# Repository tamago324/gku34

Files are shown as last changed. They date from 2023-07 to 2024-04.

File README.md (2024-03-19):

# gku34

* 狭ピッチ
  * キーピッチが縦17mmx横18mm
* KiCad 6 で作成
* [horizon プラグイン](https://github.com/skarrmann/horizon/blob/5833ec133d5f8fa4f3824622efd5dbfc89d797ec/kicad-plugins/horizon-board-producer-plugin.py)を使ってボトムプレートを生成
* choc v1 (rev0.1, rev0.2)
* Lofree switch (rev0.3)

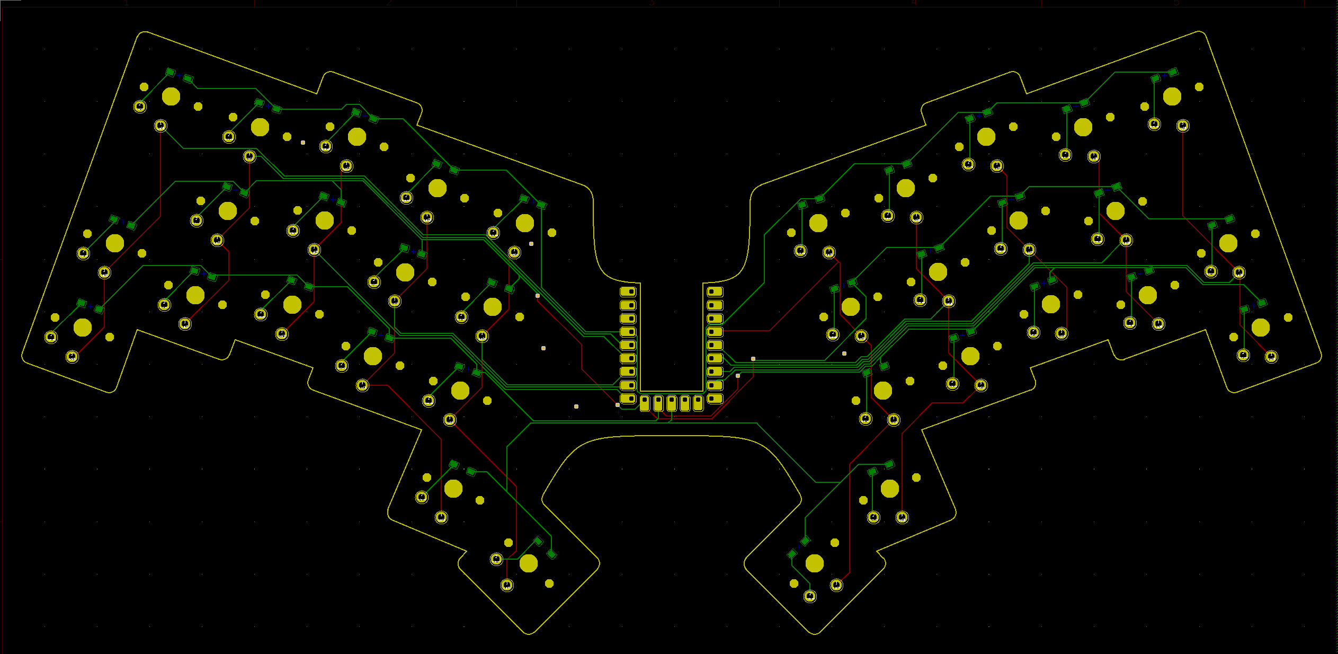
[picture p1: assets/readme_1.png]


## LICENSE

<br />この作品は <a rel="license" href="http://creativecommons.org/licenses/by/4.0/">クリエイティブ・コモンズ 表示 4.0 国際 ライセンス</a>の下に提供されています。

> 共有 — どのようなメディアやフォーマットでも資料を複製したり、再配布できます。
> 
> 翻案 — マテリアルをリミックスしたり、改変したり、別の作品のベースにしたりできます。営利目的も含め、どのような目的でも。

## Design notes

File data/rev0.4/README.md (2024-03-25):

* [Lofree スイッチ](https://www.lofree.co/products/lofree-x-kailh-full-pom-low-profile-switches)を使えるようにした
  * Choc V1 も使える
* rev0.3 との違い
  * 配線をF.cu側に集めた
    * スイッチの交換をするときに、配線に傷がつかないようにするため

## 発注するとき (JLCPCB)

* 基板
  * main_pcb (メイン基板)
    * `gerbers/main_pcb/gku34_247.632052x114.711068mm_for_JLCPCB.zip`
      * PCB Thickness: 1.6mm
      * Remove Order Number: Specify a location
  * bottom_plate (ボトムプレート)
    * `gerbers/bottom_plate/gku34-bottom-plate_247.632052x114.711068mm_for_JLCPCB.zip`
      * PCB Thickness: 1.6mm
      * Remove Order Number: Specify a location
* トッププレート
  * `stl/gku34-top-plate-jlcpcb.stl`
    * 3D Technology: MJF(Nylon)
    * Material: PA12-HP Nylon
    * Color: Black

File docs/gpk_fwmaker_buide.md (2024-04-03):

## GPK FWMaker でのビルド方法について

QMK のファームウェアをビルドするために[GPK FWMaker](https://github.com/darakuneko/gpk_fwmaker) が使用できます。
Docker を使用して簡単にビルドできるのでオススメです。

### Docker のインストール

https://www.docker.com/ から環境にあったものをダウンロードし、インストールします。

インストールが完了したらPCの再起動します。

### GPK FWMaker のダウンロード

https://github.com/darakuneko/gpk_fwmaker/archive/refs/heads/main.zip でダウンロードします。

### 初期セットアップ

ダウンロードしたディレクトリに移動し、

```
cd gpk_fwmaker
docker compose build
```

を実行。

### ツールの起動

```
cd gpk_fwmaker
docker compose up -d
```

### QMKのキーボードディレクトリをコピーする

GPKFW ディレクトリに QMKの [keyboards/tamago324/gku34](https://github.com/tamago324/qmk_firmware/tree/tamago324_v2/keyboards/tamago324/gku34) ディレクトリを、環境に合わせて以下のディレクトリにコピーする

windows: `C:\Users\xxxx\GPKFW`
mac: `/Users/xxxx/GPKFW`
ubuntu: `/home/xxxx/GPKFW`

例えば、Windows の場合、`C:\Users\xxxx\GPKFW\gku34` にコピーする

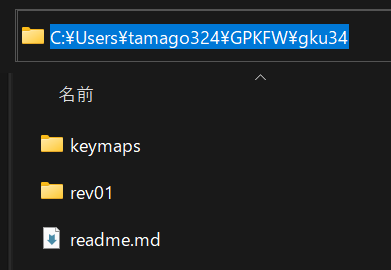
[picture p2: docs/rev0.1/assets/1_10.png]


### ファームウェアの作成

以下のコマンドを実行し、ファームウェアを作成する

Windows の場合:

```
# qmk の場合
curl -X POST -H "Content-Type: application/json" -d "{\"kb\": \"gku34/rev01\", \"km\": \"default\", \"tag\": \"0.21.5\"}" 127.0.0.1:3123/build/qmk

# vial の場合
curl -X POST -H "Content-Type: application/json" -d "{\"kb\": \"gku34/rev01\", \"km\": \"vial\"}" 127.0.0.1:3123/build/vial
```

`C:\Users\xxxx\GPKFW` に `gku34_rev01_default.uf2` が生成される

Linux の場合:

```
# qmk
curl -X POST -H "Content-Type: application/json" -d '{"kb": "gku34/rev01", "km": "tamago324", "tag": "0.21.5"}" 127.0.0.1:3123/build/qmk

# vial
curl -X POST -H "Content-Type: application/json" -d '{"kb": "gku34/rev01", "km": "vial"}' 127.0.0.1:3123/build/vial
```

### ファームウェアの書き込み

RP2040-Zero の左側のボタンを押しながら、USB を接続する

新しいデバイスとしてファイルエクスプローラに表示された、キーボードに生成された `gku34_rev01_default.uf2` をコピーします。コピーが完了すると、デバイスが切断されます。

デバイスが切断されたら、ファームウェアの書き込みが完了です。

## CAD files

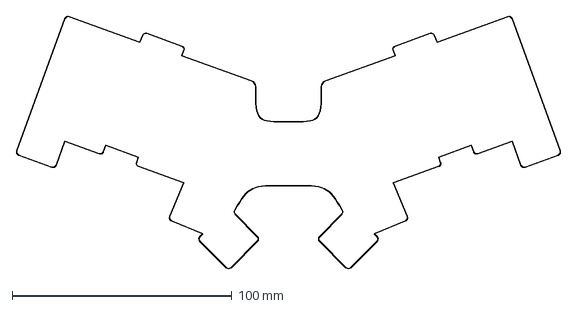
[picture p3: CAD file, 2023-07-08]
data/rev0.4/dxf/edge-bottom.dxf
248.0 x 115.1 mm

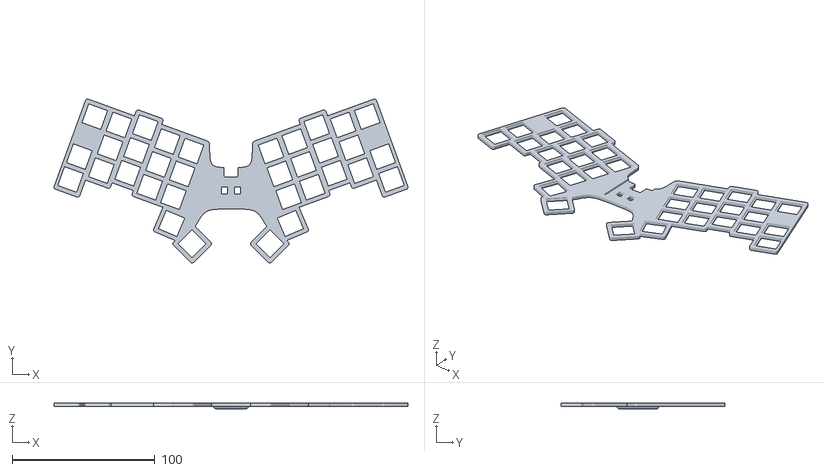
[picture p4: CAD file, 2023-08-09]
data/rev0.4/stl/gku34-top-plate-jlcpcb.stl
247.6 x 114.8 x 4.00

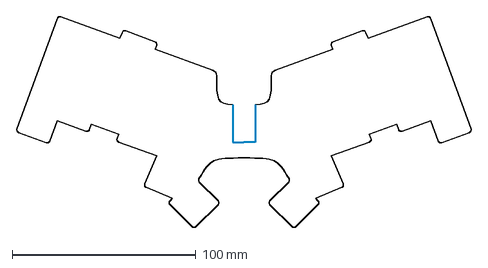
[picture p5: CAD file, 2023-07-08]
data/rev0.4/dxf/edge-pcb.dxf
248.0 x 115.1 mm

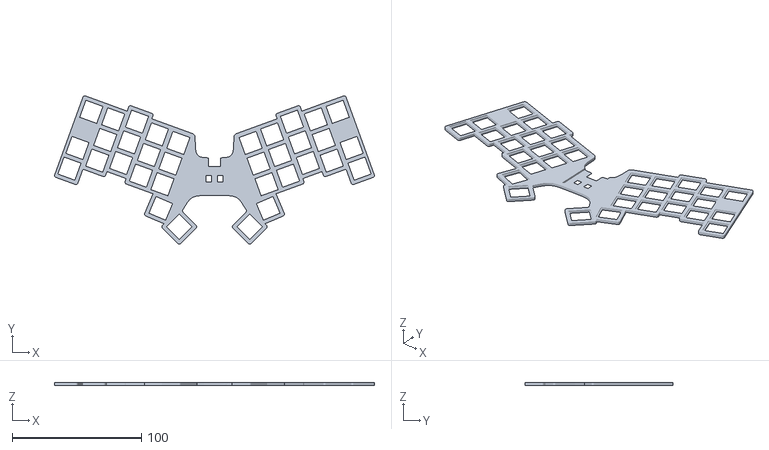
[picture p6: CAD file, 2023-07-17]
data/rev0.4/stl/gku34-top-plate.stl
247.6 x 114.8 x 2.20

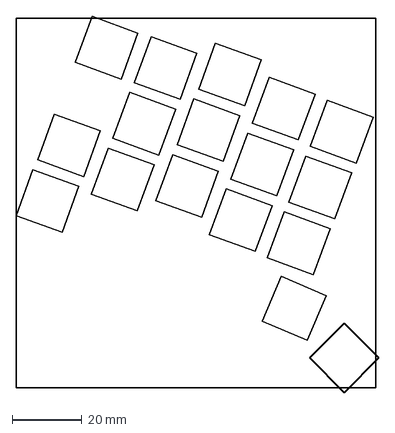
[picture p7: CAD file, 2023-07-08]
data/rev0.4/dxf/layout-base.dxf
103.9 x 107.8 mm

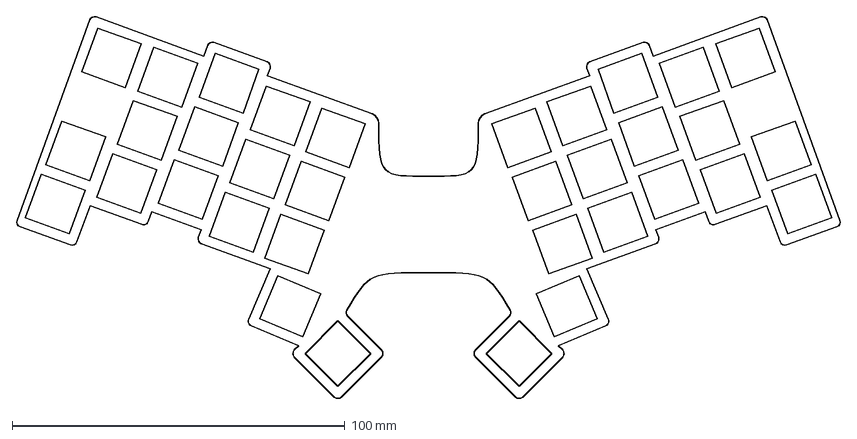
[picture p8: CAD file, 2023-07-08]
data/rev0.4/dxf/support.dxf
248.0 x 115.1 mm

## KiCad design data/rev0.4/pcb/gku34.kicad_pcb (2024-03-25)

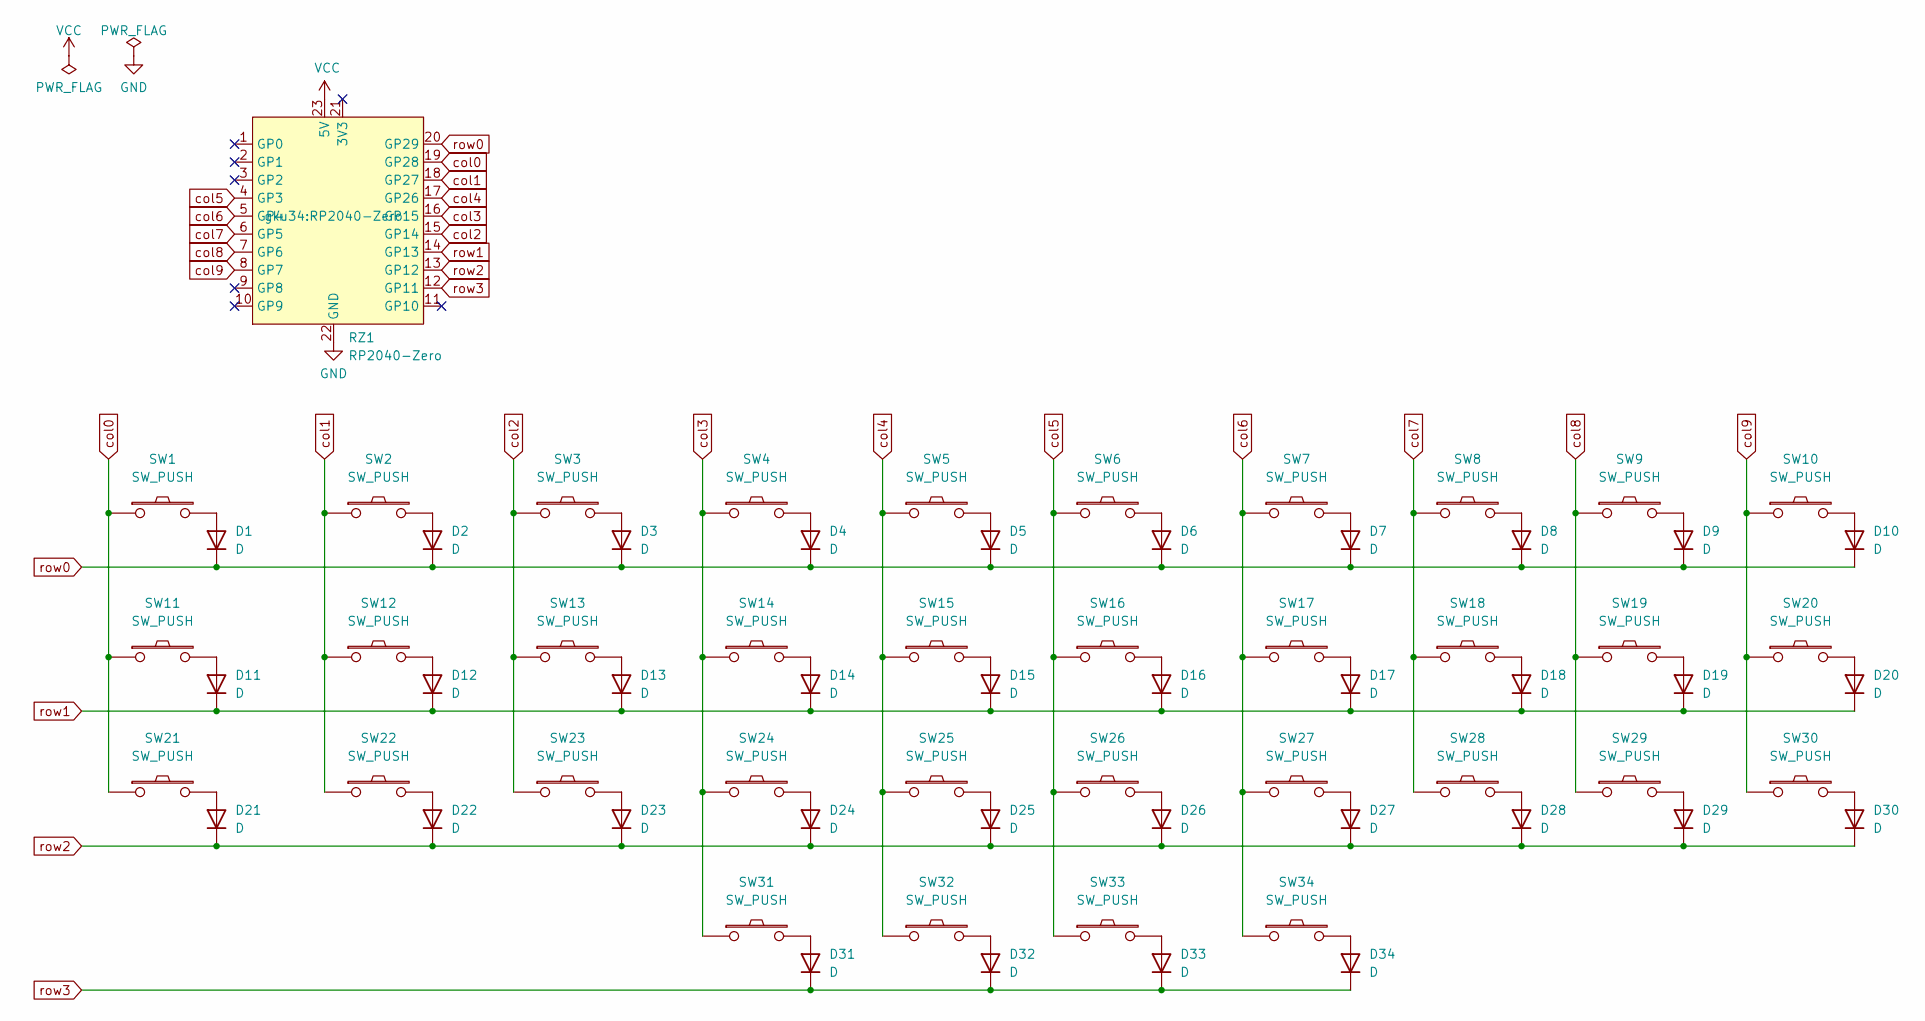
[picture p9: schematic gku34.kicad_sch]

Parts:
D1, D2, D3, D4, D5, D6, D7, D8, D9, D10, D11, D12, D13, D14, D15, D16, D17, D18, D19, D20, D21, D22, D23, D24, D25, D26, D27, D28, D29, D30, D31, D32, D33, D34: D; Diode_SMD
RZ1: RP2040-Zero
SW1, SW2, SW3, SW4, SW5, SW6, SW7, SW8, SW9, SW10, SW11, SW12, SW13, SW14, SW15, SW16, SW17, SW18, SW19, SW20, SW21, SW22, SW23, SW24, SW25, SW26, SW27, SW28, SW29, SW30, SW31, SW32, SW33, SW34: SW_PUSH; SW_Choc

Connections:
GND: RZ1.22 (GND)
unnamed: D1.2 (A), SW1.2
unnamed: D2.2 (A), SW2.2
unnamed: D3.2 (A), SW3.2
unnamed: D4.2 (A), SW4.2
unnamed: D5.2 (A), SW5.2
unnamed: D6.2 (A), SW6.2
unnamed: D7.2 (A), SW7.2
unnamed: D8.2 (A), SW8.2
unnamed: D9.2 (A), SW9.2
unnamed 10: D10.2 (A), SW10.2; also elsewhere on the board
unnamed: D11.2 (A), SW11.2
unnamed: D12.2 (A), SW12.2
unnamed: D13.2 (A), SW13.2
unnamed: D14.2 (A), SW14.2
unnamed: D15.2 (A), SW15.2
unnamed: D16.2 (A), SW16.2
unnamed: D17.2 (A), SW17.2
unnamed: D18.2 (A), SW18.2
unnamed: D19.2 (A), SW19.2
unnamed: D20.2 (A), SW20.2
unnamed: D21.2 (A), SW21.2
unnamed: D22.2 (A), SW22.2
unnamed: D23.2 (A), SW23.2
unnamed: D24.2 (A), SW24.2
unnamed: D25.2 (A), SW25.2
unnamed: D26.2 (A), SW26.2
unnamed: D27.2 (A), SW27.2
unnamed: D28.2 (A), SW28.2
unnamed: D29.2 (A), SW29.2
unnamed: D30.2 (A), SW30.2
unnamed: D31.2 (A), SW31.2
unnamed: D32.2 (A), SW32.2
unnamed: D33.2 (A), SW33.2
unnamed: D34.2 (A), SW34.2
VCC: RZ1.23 (5V)
col0: RZ1.19 (GP28), SW1.1, SW11.1, SW21.1
col1: RZ1.18 (GP27), SW2.1, SW12.1, SW22.1
col2: RZ1.15 (GP14), SW3.1, SW13.1, SW23.1
col3: RZ1.16 (GP15), SW4.1, SW14.1, SW24.1, SW31.1
col4: RZ1.17 (GP26), SW5.1, SW15.1, SW25.1, SW32.1
col5: RZ1.4 (GP3), SW6.1, SW16.1, SW26.1, SW33.1
col6: RZ1.5 (GP4), SW7.1, SW17.1, SW27.1, SW34.1
col7: RZ1.6 (GP5), SW8.1, SW18.1, SW28.1
col8: RZ1.7 (GP6), SW9.1, SW19.1, SW29.1
col9: RZ1.8 (GP7), SW10.1, SW20.1, SW30.1; also elsewhere on the board
row0: D1.1 (K), D2.1 (K), D3.1 (K), D4.1 (K), D5.1 (K), D6.1 (K), D7.1 (K), D8.1 (K), D9.1 (K), D10.1 (K), RZ1.20 (GP29)
row1: D11.1 (K), D12.1 (K), D13.1 (K), D14.1 (K), D15.1 (K), D16.1 (K), D17.1 (K), D18.1 (K), D19.1 (K), D20.1 (K), RZ1.14 (GP13)
row2: D21.1 (K), D22.1 (K), D23.1 (K), D24.1 (K), D25.1 (K), D26.1 (K), D27.1 (K), D28.1 (K), D29.1 (K), D30.1 (K), RZ1.13 (GP12)
row3: D31.1 (K), D32.1 (K), D33.1 (K), D34.1 (K), RZ1.12 (GP11)

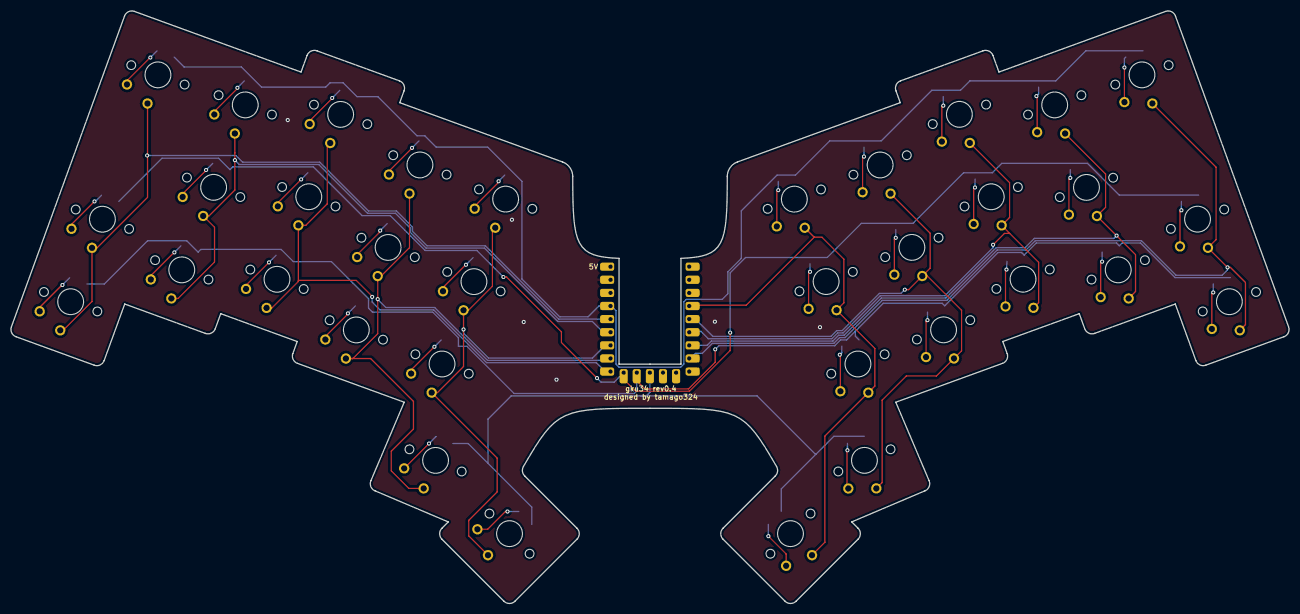
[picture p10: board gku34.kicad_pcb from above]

Board: 2 copper layers, 247.6 x 114.8 mm, 69 parts (0 on the bottom side), 48 nets.

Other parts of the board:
SWe: SW_PUSH; SW_Choc_V2

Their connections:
unnamed 10: SWe.2; also elsewhere on the board
col9: SWe.1; also elsewhere on the board

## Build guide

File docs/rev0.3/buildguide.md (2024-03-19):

# gku34 ビルドガイド

gku34 rev0.3 のビルドガイドです。 (rev0.2との変更点は [Lofree スイッチ](https://www.lofree.co/products/lofree-x-kailh-full-pom-low-profile-switches)を使えるようにした点のみ)

<details><summary>目次</summary><div>

* [キットに含まれるもの](#キットに含まれるもの)
* [キット以外に必要なもの](#キット以外に必要なもの)
* [組み立て順序の確認](#組み立て順序の確認)
* [組み立て](#組み立て)
  * [1. プレートの側面をペンで塗る](#1プレートの側面をペンで塗る)
  * [2. RP2040-Zero のボタンをペンで塗る](#2rp2040-zero-のボタンをペンで塗る)
  * [3. ダイオードのはんだ付け](#3-ダイオードのはんだ付け)
  * [4. RP2040-Zero のはんだ付け](#4-rp2040-zero-のはんだ付け)
  * [5. 動作確認](#5-動作確認)
  * [6. スイッチのはんだ付け](#6-スイッチのはんだ付け)
  * [7. ボトムプレートを取り付ける](#7-ボトムプレートを取り付ける)
  * [8. ゴム足を取り付ける](#8-ゴム足を取り付ける)
  * [9. キーキャップを取り付ける](#9-キーキャップを取り付ける)
  * [10. キーマップの変更](#10-キーマップの変更)
* [最後に](#最後に)

</div></details>

## キットに含まれるもの

| No. | 名前 | 数量 | 備考 |
|-----|---|---|---|
| 1 | PCB | 1枚 | メインPCB |
| 2 | ボトムプレート | 1枚 | ボトムプレート |
| 3 | トッププレート | 1枚 | JLCPCBで製造してもらった3Dプリント製のトッププレート |
| 4 | ダイオード | 34個 + 予備 | [遊舎工房](https://shop.yushakobo.jp/collections/all-keyboard-parts/products/a0800di-02-100)で購入できます。 |
| 5 | ゴム足 | 10個 | [Amazon](https://amzn.asia/d/dPdWZld)で購入できます。 |
| 6 | 両面テープ (5mm幅) | - | PCBとボトムプレートを張り合わせるために使用。 <br>[Amazon](https://amzn.asia/d/8XeKmsn)で購入できます。 |
| 7 | ピンヘッダ | - | RP2040-Zero をまっすぐはんだ付けするために使用するピンヘッダ |

## キット以外に必要なもの

| 名前 | 数量 | 備考 |
|---|---|---|
| RP2040-Zero | 1個 |[スイッチサイエンス](https://www.switch-science.com/products/7886/) などで購入できます。 |
| キーキャップ | 34個 | choc v1用、またはMX用キーキャップ<br>Lofreeスイッチを取り付ける場合、Junana MX キーキャップがおすすめです。([1U 凹形](https://booth.pm/ja/items/5551574)、[1U 凸形](https://booth.pm/ja/items/5551877))  |
| キースイッチ | 34個 | choc v1スイッチ、または [Lofree スイッチ](https://www.lofree.co/products/lofree-x-kailh-full-pom-low-profile-switches) |
| USBケーブル | 1個  | Type-C の USBケーブル |

## 組み立て順序の確認

1. プレートの側面をペンで塗る
2. RP2040-Zero のボタンをペンで塗る
3. ダイオードのはんだ付け
4. RP2040-Zero のはんだ付け
5. 動作確認
6. スイッチのはんだ付け
7. ボトムプレートを取り付ける
8. ゴム足を取り付ける
9. キーキャップを取り付ける
10. キーマップの変更

## 組み立て

### 1. プレートの側面をペンで塗る

PCB と ボトムプレートの側面を[ポスカ](https://amzn.asia/d/1ZZTGt9)などのペンで塗ります。

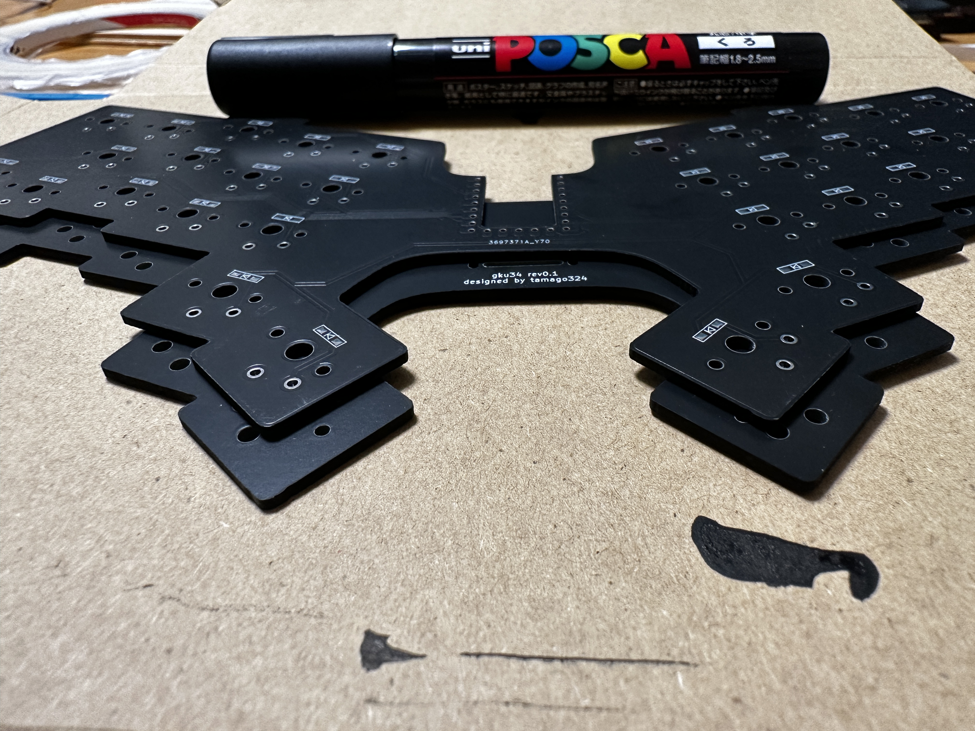
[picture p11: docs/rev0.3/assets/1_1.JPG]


### 2. RP2040-Zero のボタンをペンで塗る

RP2040-Zero のボタンを[マッキー](https://amzn.asia/d/gaXAFb8)などのペンで塗ります。

これをすることにより、トッププレートを合わせたときに真っ黒になります。

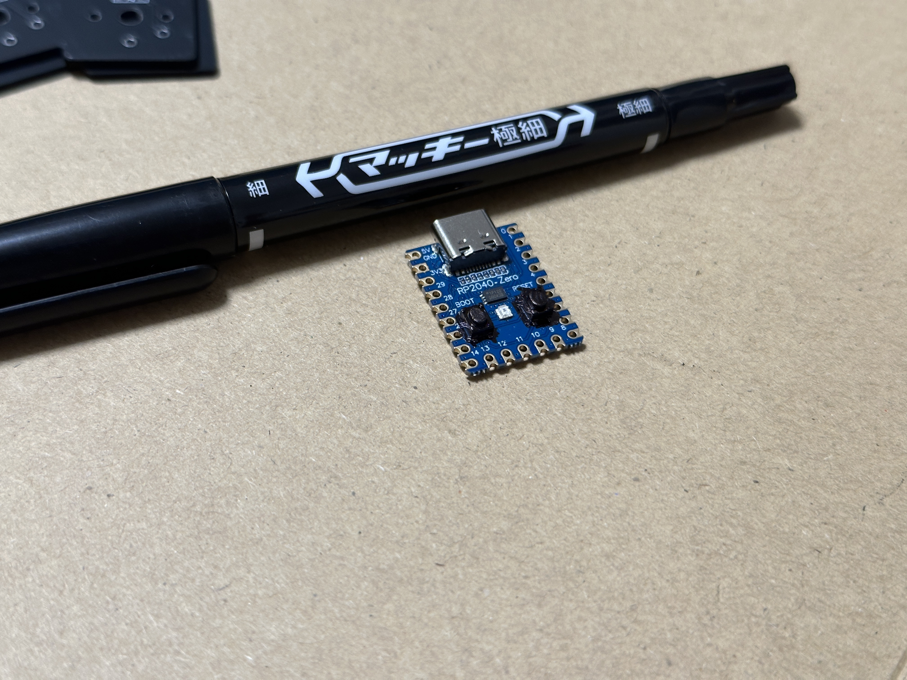
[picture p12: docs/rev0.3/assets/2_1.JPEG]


### 3. ダイオードのはんだ付け

PCBの裏にダイオードを34個はんだ付けします。
「PCBのシルクの線」と「ダイオードの線」が一致するようにはんだ付けします。
はんだごての温度は320℃くらいに設定し作業します。

片側に予備ハンダを行い、
ピンセットを使用して、はんだ付けを行い、
もう片方もはんだ付けします。

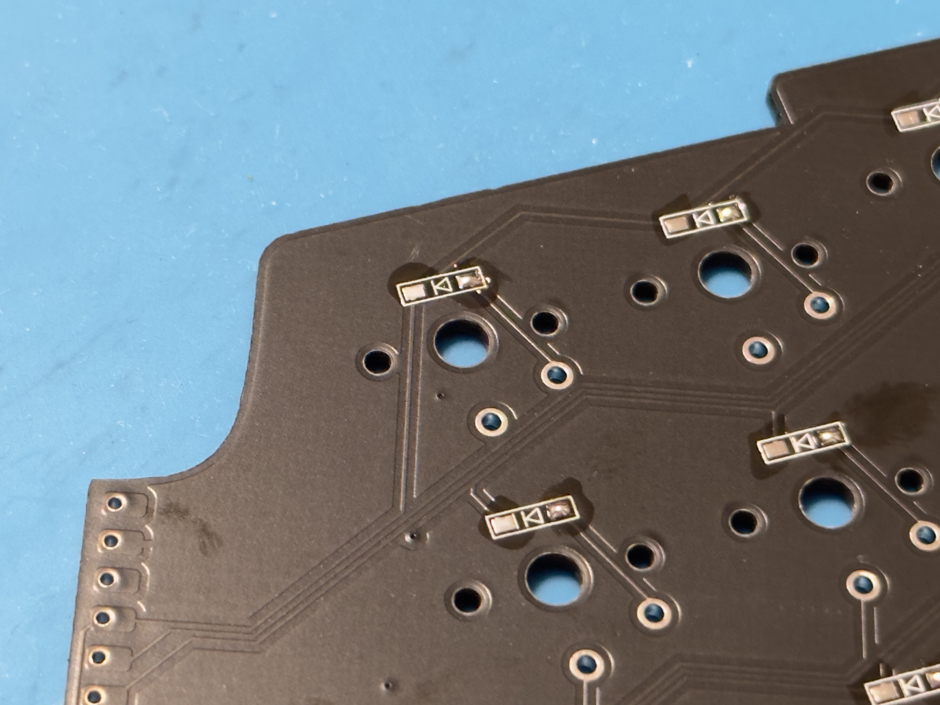
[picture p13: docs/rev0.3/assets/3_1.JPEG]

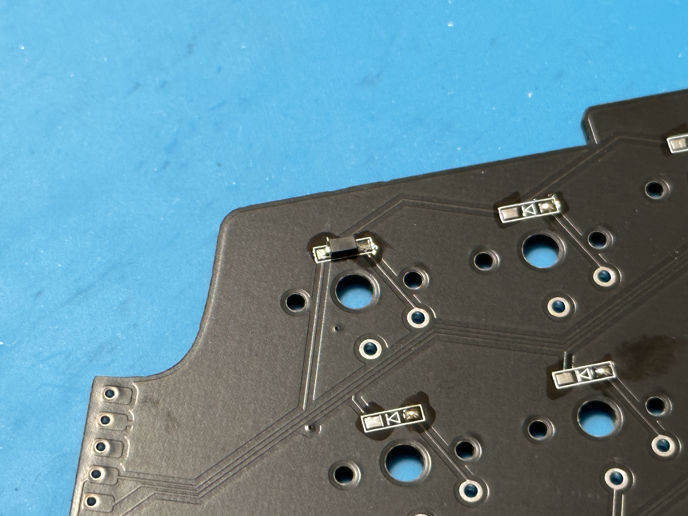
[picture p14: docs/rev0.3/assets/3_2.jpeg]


すべてのダイオードのはんだ付けが終わったら、すべてのダイオードが同じ向きになっていることを確認してください。

### 4. RP2040-Zero のはんだ付け

「PCB の表面の 5V」が「RP2040-Zero の 5V」にあうように合わせます。

ピンヘッダを RP2040-Zero と PCB に刺して、まっすぐなるように合わせます。

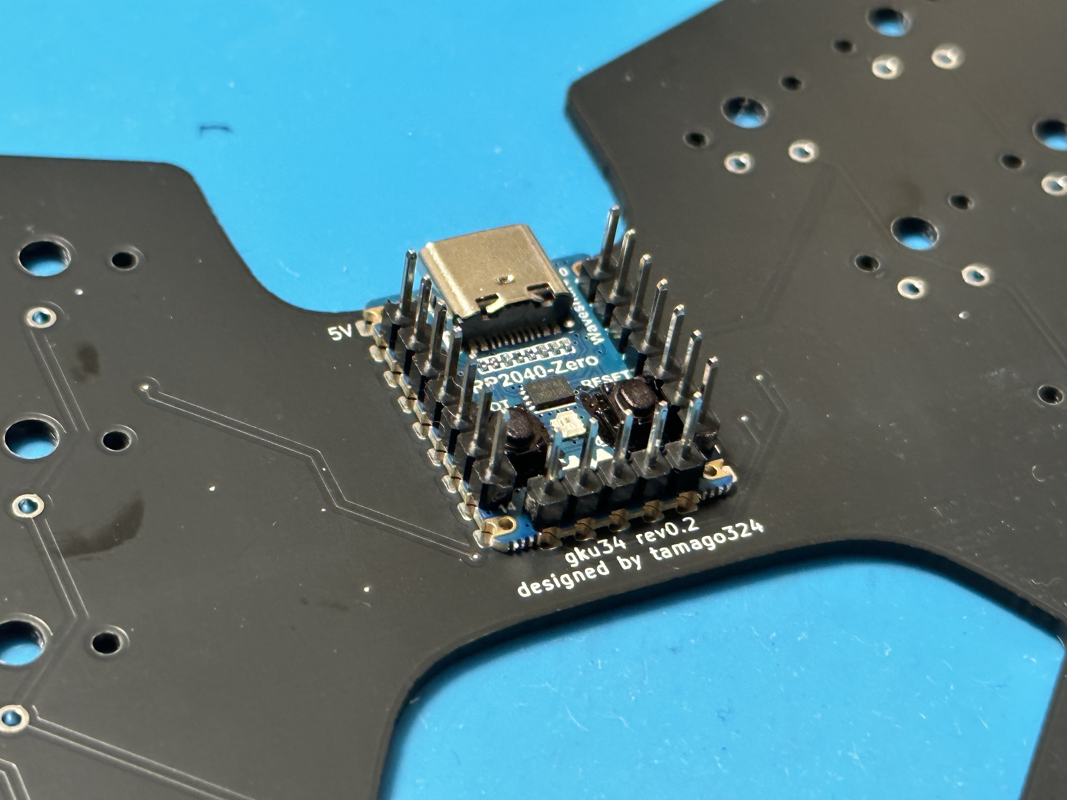
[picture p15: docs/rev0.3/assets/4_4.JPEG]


RP2040-Zero の角を4箇所はんだ付けをし、浮いていないことを確認してから、すべてをはんだ付けします。

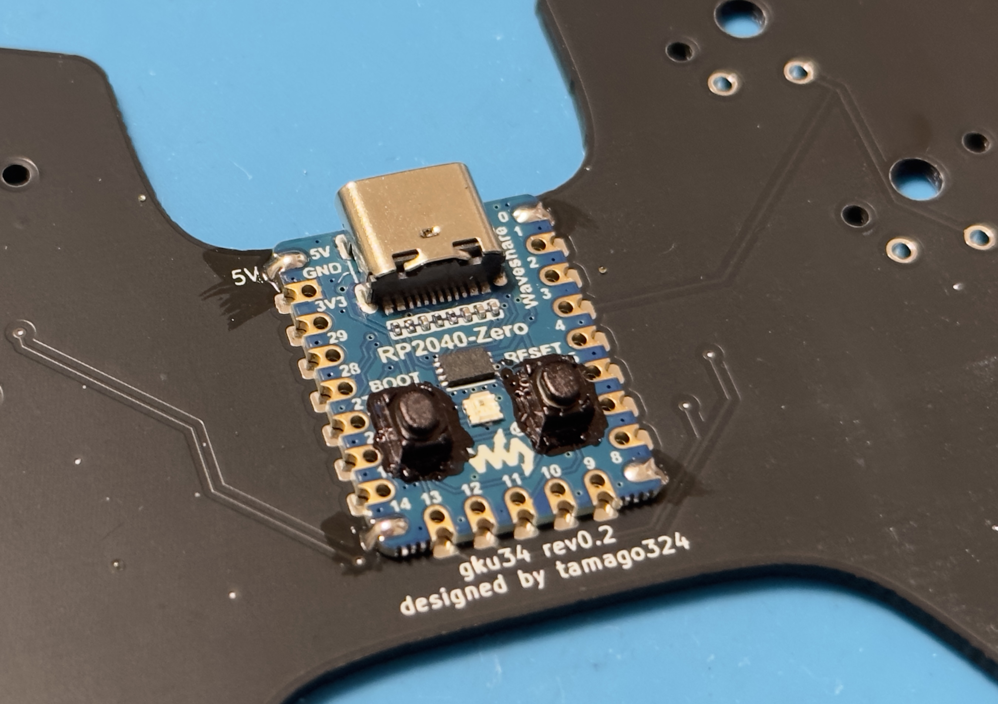
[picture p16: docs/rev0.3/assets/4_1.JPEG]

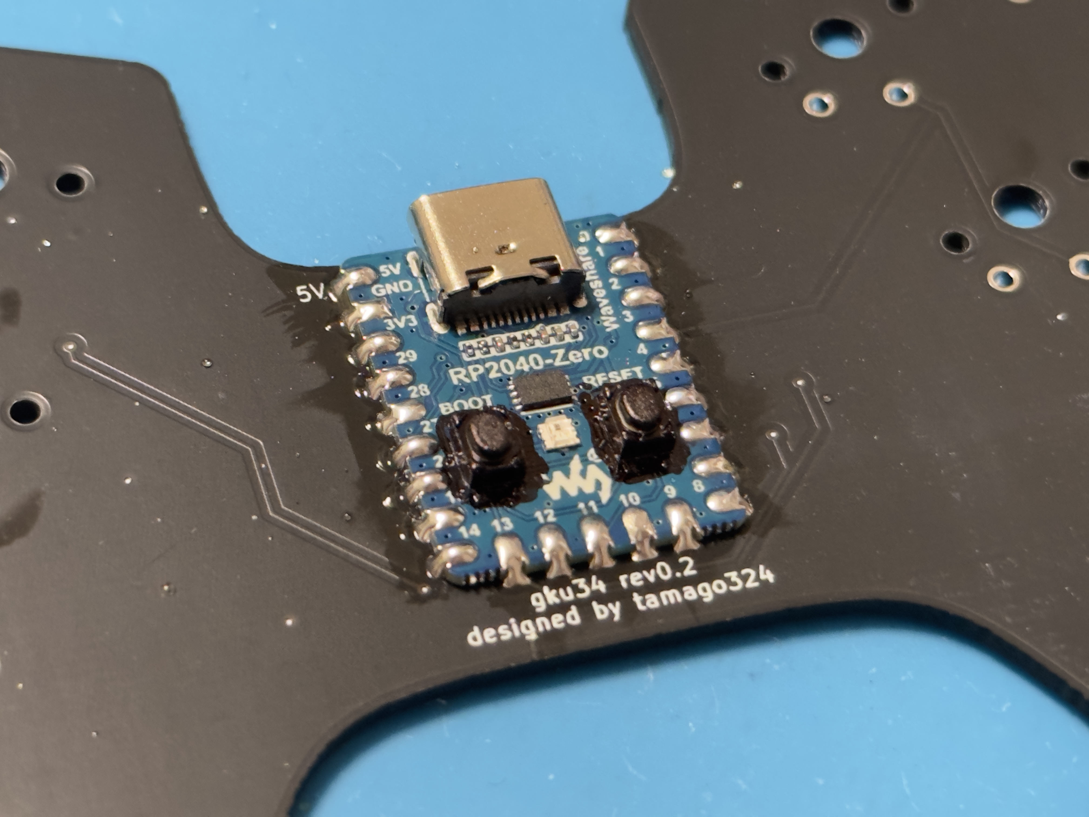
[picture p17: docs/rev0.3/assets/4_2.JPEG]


### 5. 動作確認

#### ファームウェアの書き込み

[Remap のファームウェア](https://remap-keys.app/catalog/Vax92NppUdpJnLsBweYy/firmware) のページからダウンロードし、

RP2040-Zero の左側のボタンを押しながら、USB を接続し、
新しいデバイスとしてファイルエクスプローラに表示されたデバイスに、ダウンロードしたファイルををコピーします。コピーが完了すると、デバイスが切断されます。
デバイスが切断されたら、ファームウェアの書き込みが完了です。

#### 入力の確認

[Remap](https://remap-keys.app/) にアクセスし、`START REMAP FOR YOUR KEYBOARD` ボタンをクリック

`+KEYBAORD` をクリックし、表示された `gku34` を選択し、`接続` をクリック

`Test Matrix Mode` をクリックし、入力の確認を行う。

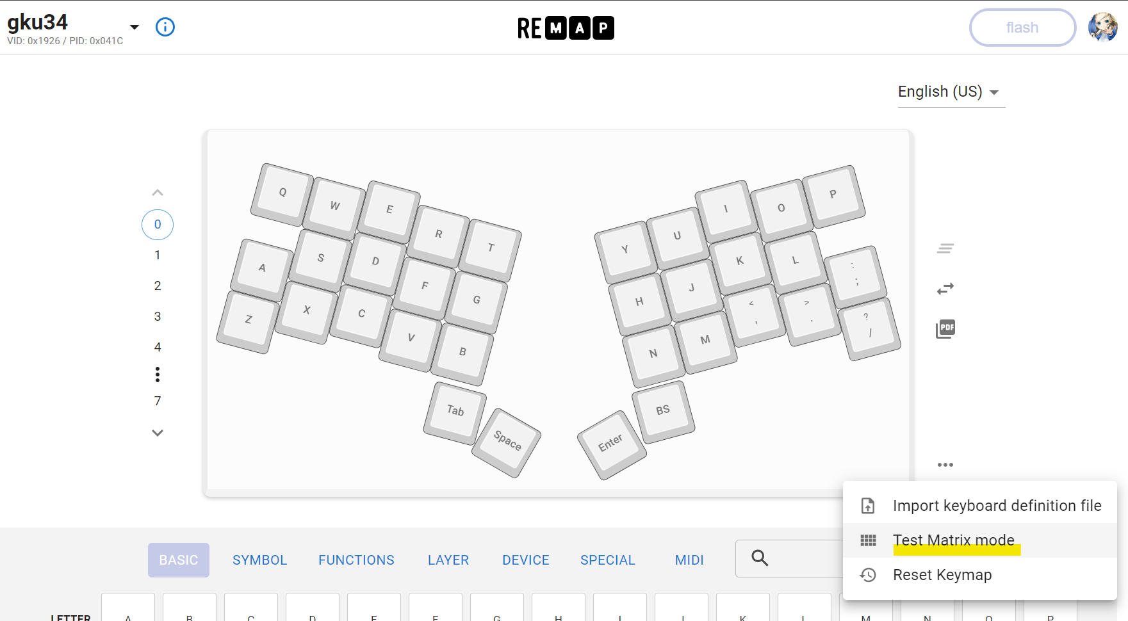
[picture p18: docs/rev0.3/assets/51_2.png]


スイッチのピンの穴をピンセットでショートさせることで入力を確認します。

### 6. スイッチのはんだ付け

rev0.3 は[Lofree スイッチ](https://www.lofree.co/products/lofree-x-kailh-full-pom-low-profile-switches)も取り付け可能です。

トッププレートとPCBを合わせて、PCBの表からスイッチを差し込み、裏からスイッチをはんだ付けします。
はんだごての温度は320℃くらいに設定し作業します。

ボトムプレートを張り付ける前に念のため、再度 Remap で入力の確認をしておきます。  
もし、入力がおかしい場合、ダイオードやスイッチの足にはんだごてをあてて、再度確認します。




### 7. ボトムプレートを取り付ける

両面テープをボトムプレートに貼り付け、PCBとボトムプレートがずれないように貼り付けます。

両面テープの貼る面は `Tape on this side` と書かれている面です。

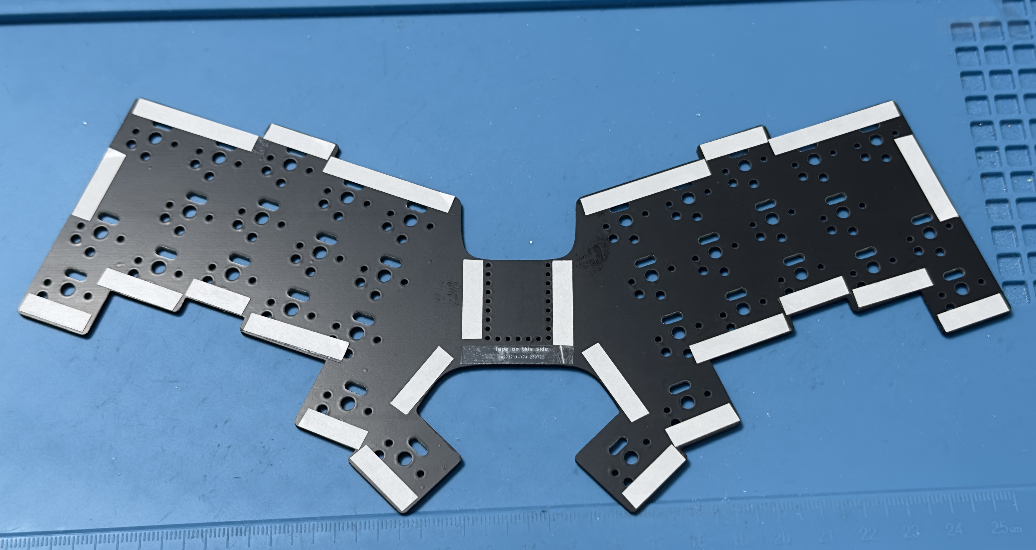
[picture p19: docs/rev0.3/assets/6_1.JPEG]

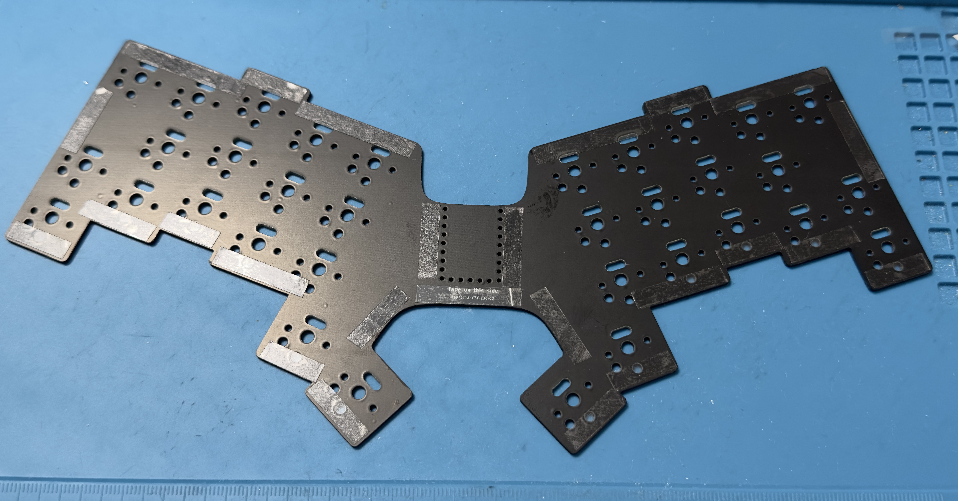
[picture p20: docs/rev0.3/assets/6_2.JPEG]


### 8. ゴム足を取り付ける

ボトムプレートにゴム足を取り付けます。

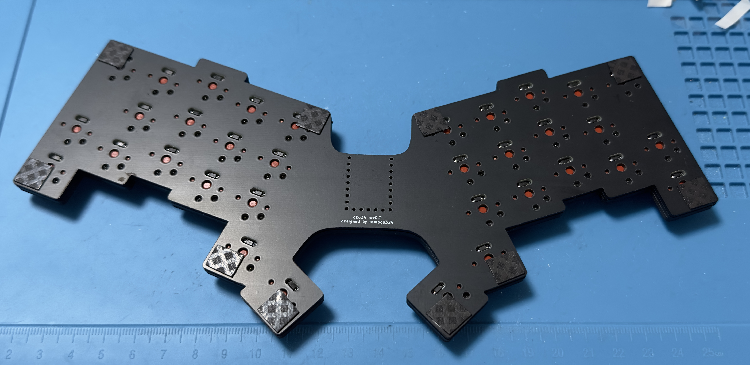
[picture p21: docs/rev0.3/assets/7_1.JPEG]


### 9. キーキャップを取り付ける

キーキャップを取り付けます。



### 10. キーマップの変更

Remap か QMK か Vial を使用してキーマップを変更可能です。
* QMK の場合: [tamago324/qmk_firmware](https://github.com/tamago324/qmk_firmware/tree/tamago324_v2/keyboards/tamago324/gku34) の `tamago324` ブランチの `keyboards/tamago324/gku34` にファームウェアがあります。また、バージョンは 0.21系です
  * GPK FWMakerでビルドして書き込む場合は[こちら](../gpk_fwmaker_buide.md)
* Vial の場合: [こちら](../../firmware/vial/gku34_rev01_vial.uf2) の uf2 ファイルをダウンロードし、書き込むことで [vial](https://get.vial.today/) を使用してキーマップの変更ができます。
  * Vial のインストールなどについては[こちら](../vial_guide.md)
  * すでに Vial のキーマップを設定している場合には、エクスポートしてから書き込んでください。Vial のキーマップがデフォルトのキーマップで上書きされてしまいます。
* Remap の場合: キーボードカタログの gku34 のページで設定可能です。

## 最後に

完成したキーボードの写真を SNS に投稿していただけるととても嬉しいです！

(ハッシュタグは `#gku34` です。)

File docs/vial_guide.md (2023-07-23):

## Vial を使ったキーマップの変更について

### Vial のインストール

https://get.vial.today/download/ にアクセスし、環境にあったインストーラーをダウンロードし、インストールする

### Vial 用のファームウェアの書き込み

[こちら](../firmware/vial/gku34_rev01_vial.uf2) のファイルをダウンロードします。

RP2040-Zero の左側のボタンを押しながら、USB を接続します。

新しいデバイスとしてファイルエクスプローラに表示されたデバイスにダウンロードしたファイルをコピーします。コピーが完了すると、デバイスが切断されます。

デバイスが切断されたら、ファームウェアの書き込みが完了です。

### Vial の起動、読み込み

Vial を起動します。

gku34 の読み込みがされていない場合、`Refresh` ボタンをクリックします。

`MANUFACTURER gku34` と表示され、gku34 のキーマップが表示されていれば、読み込み完了です。

キーマップの変更が可能です。

### おすすめの設定

少ないキーのキーボードを使用する際に、設定しておきたい項目について説明します。

`QMK Settings > Tap-Hold` タブの項目を設定すると単体押し、長押しの感覚などの設定ができるので、おすすめです。

* `Tapping Term`: 140 など、使いやすい数値に変更します
  * 長押しとして判定するまでの時間です
* `Ignore Mod Tap Interput`: ON にします
  * Mod Tap Key と通常キーを連続して拘束に押したときに両方のキーを Tap として扱う
* `Tapping Force Hold`: ON にします
  * 例えば、`LSFT_T(KC_SPACE)` としていたときに、 `Space` 単体押し直後に `Space` 長押し としたときに、`Space` が連続で入力されてしまう問題が改善されます。

#### 参考文献

* [Ergodox(qmk firmware)の同時押し/レイヤー切替の設定メモ](https://qiita.com/uodna/items/6d23581d26c1adb23377)
* [QMKの「タップ」と「ホールド」を極める - golden-luckyの日記](https://golden-lucky.hatenablog.com/entry/2021/03/06/182958)
* [タップホールド設定](https://docs.qmk.fm/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)

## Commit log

2023-07-17 update top-plate
    [gku34-rev0.1-top-plate-v2.stl, gku34-rev0.1-top-plate.stl]
2023-07-21 add rev0.2
    [edge-bottom.dxf, edge-pcb.dxf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]
2023-07-29 fix top plate stl file
    [gku34-top-plate.stl]
2023-08-09 add: jlcpcb top-plate
    [gku34-top-plate-jlcpcb.stl]
2024-03-19 rev0.3 を追加
    [edge-bottom.dxf, edge-pcb.dxf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]
2024-03-19 ドキュメントの更新
2024-03-19 おすすめキーキャップについて追記
2024-03-25 rev0.4追加
    [edge-bottom.dxf, edge-pcb.dxf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]
2024-04-03 update vial_firmware
    QとE を押すことで unlock できるように対応
2024-04-03 マウスキーを有効化

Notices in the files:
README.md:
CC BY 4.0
